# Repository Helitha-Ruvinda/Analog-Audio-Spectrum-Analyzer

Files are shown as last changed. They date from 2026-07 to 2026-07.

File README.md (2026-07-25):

# 10-Band Analog Audio Spectrum Analyzer

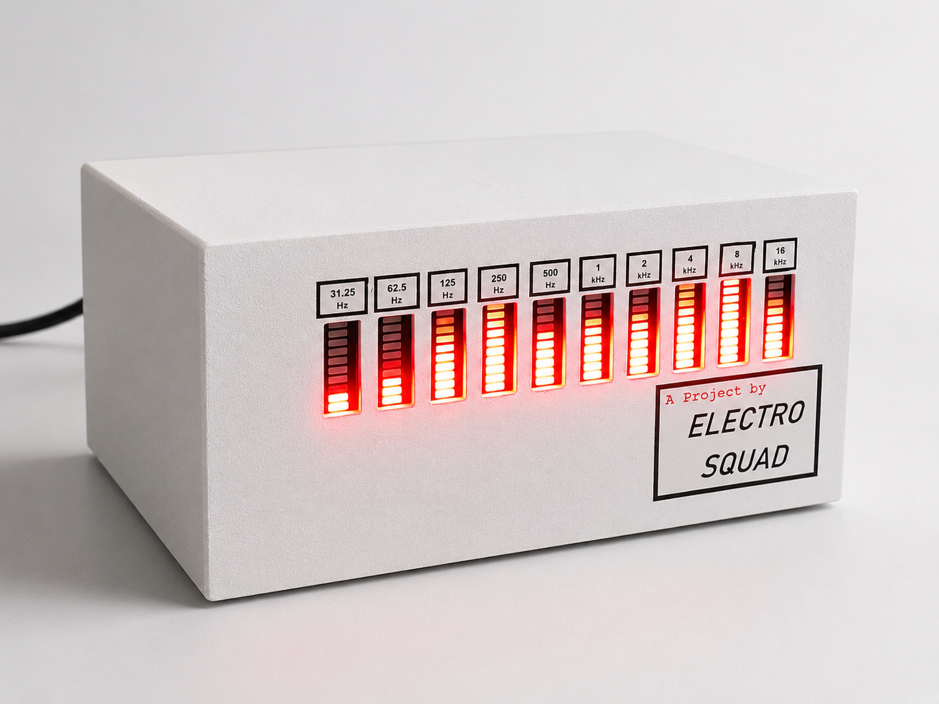
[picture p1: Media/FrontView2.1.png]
Project Front View


## Overview
This repository contains the complete hardware design, schematics, and testing documentation for a fully analog 10-band audio spectrum analyzer. The system processes incoming audio signals, isolates specific frequency bands, and visually maps the amplitude of each band using LED bar graphs. 

This project demonstrates full-stack analog hardware design from theoretical calculations to physical breadboard prototyping.

## Working Demonstration
Watch the fully analog analyzer in action below:

https://github.com/user-attachments/assets/5d2a667e-e02e-4562-982c-1e00bb6419e8

---

## System Architecture
The circuit avoids digital processing and relies entirely on precision analog components, divided into three core stages:

*   **Filter Stage:** Second-order Multiple Feedback (MFB) Band Pass Filters isolate 10 distinct audio frequency bands across the human hearing spectrum.
*   **Peak Detector Stage:** Precision Op-Amp based peak detectors capture the maximum amplitude of the filtered AC signals to provide a stable DC voltage for the display.
*   **Display Driver Stage:** LM3914 LED driver ICs, configured in "bar mode," map the analog voltage levels to 10-segment LED columns.

---

## Contribution
Team ElectroSquad
Department of Electronic and Telecommunication Engineering (ENTC)  
University of Moratuwa

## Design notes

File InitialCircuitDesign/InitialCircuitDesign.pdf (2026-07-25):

Single chanel

Filter.

This is a second order MFB (Multiple feed back Band Pass Filter). By changing R2, C1, C2, C3 we can change the cut-off frequency.

Peak Detector.

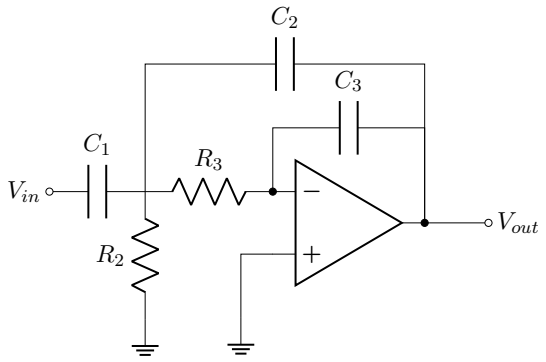
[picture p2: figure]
Vin; Vout

We need to examine how the peales change in each frequency component so that we can display them. for more reliable resault we use Op Amp based peale defector rather than single diode peale detector.

Comparator.

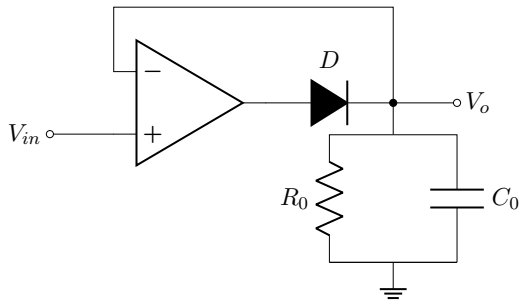
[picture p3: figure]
Vin

We need to map peale detector output to number of leds which is proportional to its amplitude. We could use Op amp compurators for this but for 10 bands which include 10 × 10 = 100 we require 100 opamps which is not practicle. Heance we use LM3914 IC has 10 comparators. This Ic has two modes. Dot & Bar mode. Let’s use bar mode for Visually apealling.

From Dadasheet;

1

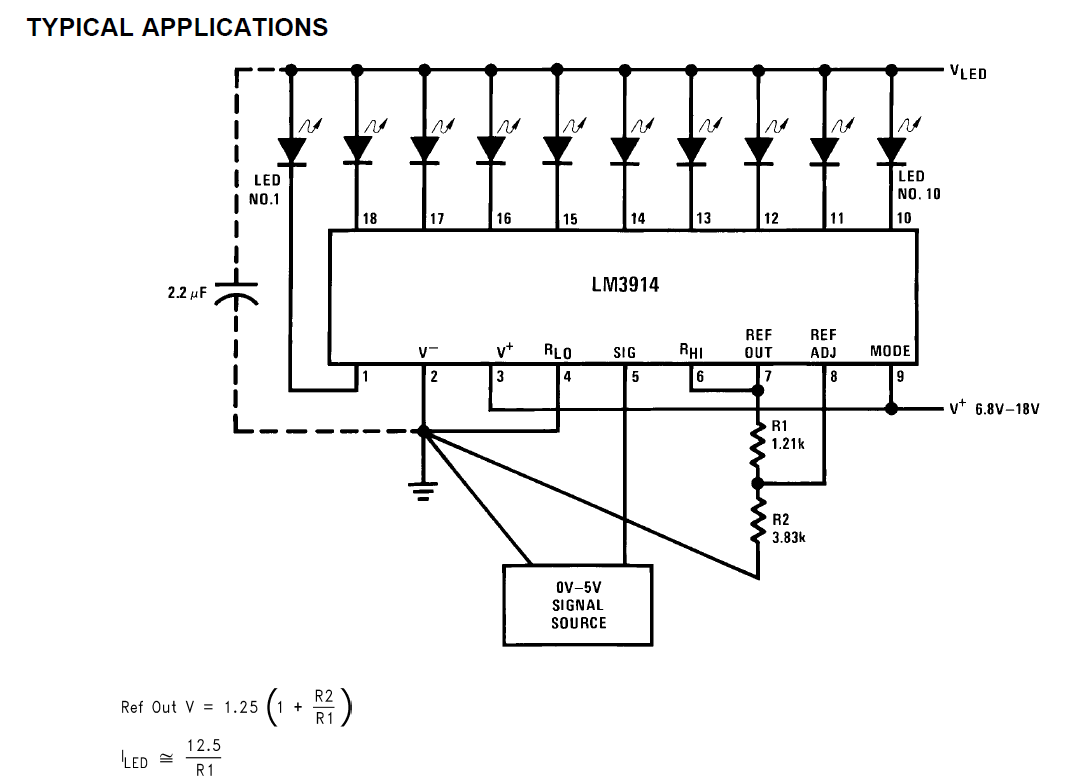
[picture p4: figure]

VRef = 1.25
1 +

R2
R1

ILED ∼=

12.5
R1

Since Audio source typical (Voud) max ≈ 2.5V Choose VRef = 2.5V = 1.25
1 + R2
R1

Hence R1 = R2

Choose current per led to be 10 mA

ILED = 10 mA =

12.5
R1

⇒ R1 = 1.25 kΩ

Combined Circuit per chanel.

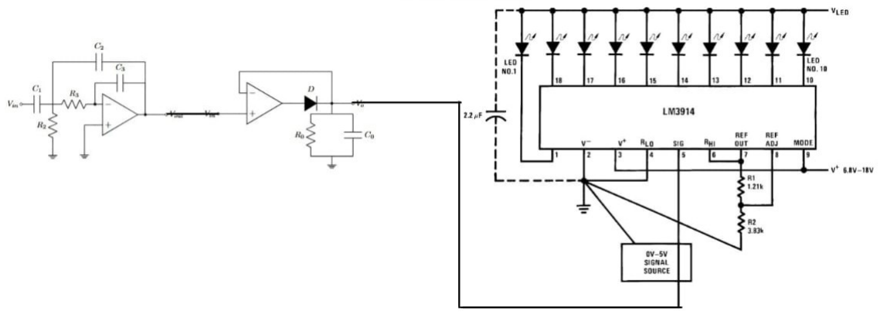
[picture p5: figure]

Repeat the above circuit to create 10 chanels. Diagram of full circuit.

2

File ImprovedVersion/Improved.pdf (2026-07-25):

## LED Matrix Display Using a Single LM3914

## Concept

Using ten LM3914 ICs is not space-efficient or cost-effective. Instead, a multiplexing technique can be employed so that a single LM3914 performs the same function.
By rapidly switching between channels, the analyzer can be extended to support up to 32 input channels while significantly reducing hardware cost and PCB area.

## System Overview

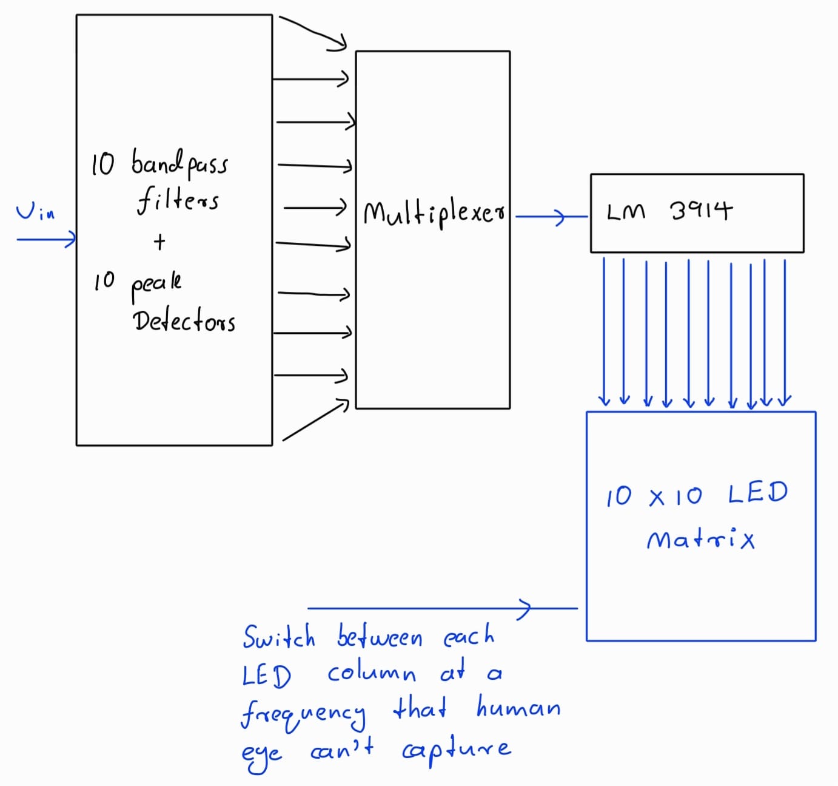
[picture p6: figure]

Figure 1: System for use single LM3914

## Operating Principle

- The input signal is divided into ten frequency bands using band-pass filters.

1

- Each filter output is processed by a peak detector.
- The ten peak voltages are sequentially selected by a multiplexer.
- The selected signal is fed into a single LM3914.
- The LM3914 drives one column of the LED matrix at a time.
- By rapidly scanning all columns, persistence of vision makes the display appear continuously illuminated.

## Advantages

- Lower component cost
- Reduced PCB area
- Easier routing
- Scalable architecture (up to 32 channels with additional multiplexing)
- Lower power consumption compared to using one LM3914 per channel

2

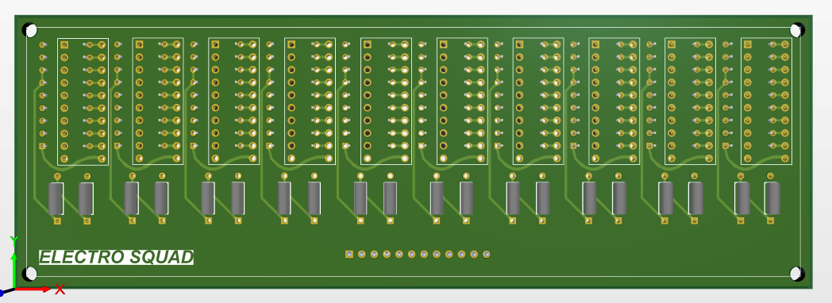
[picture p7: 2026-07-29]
DesignFiles/Altium/LedDriverCircuit-3D-Front.png

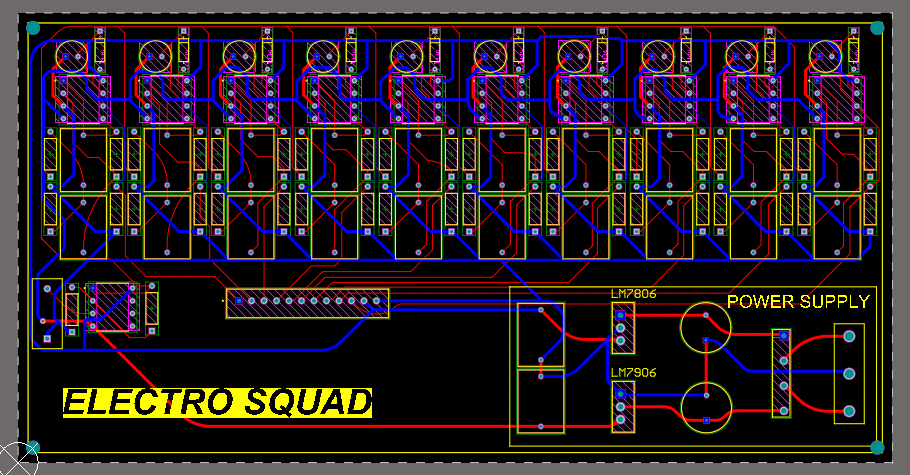
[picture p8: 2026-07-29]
DesignFiles/Altium/FilterCircuit-2D.png

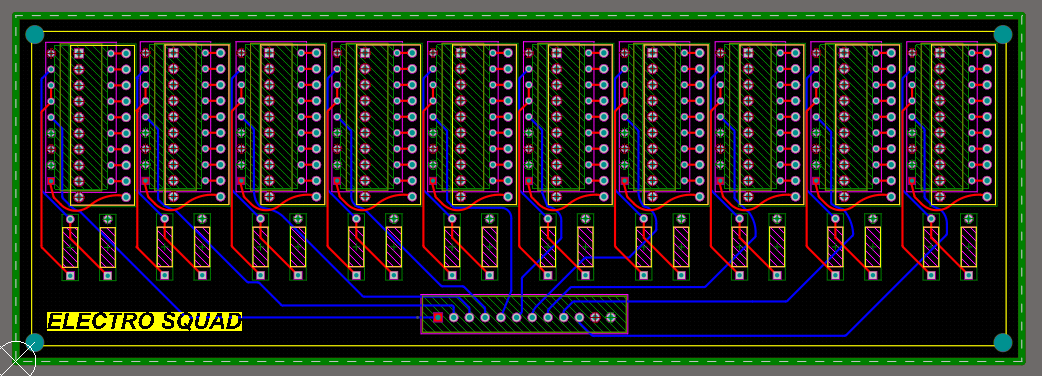
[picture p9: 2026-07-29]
DesignFiles/Altium/LedDriverCircuit-2D.png

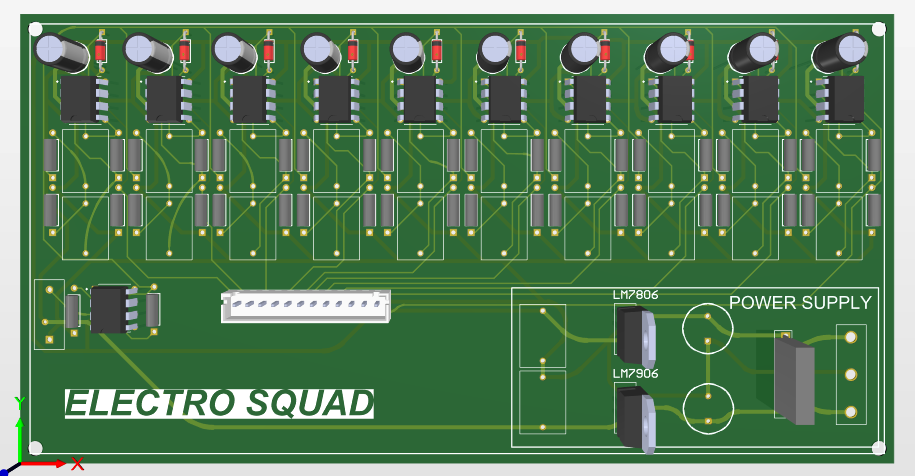
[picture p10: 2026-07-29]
DesignFiles/Altium/FilterCircuit-3D-Front.png

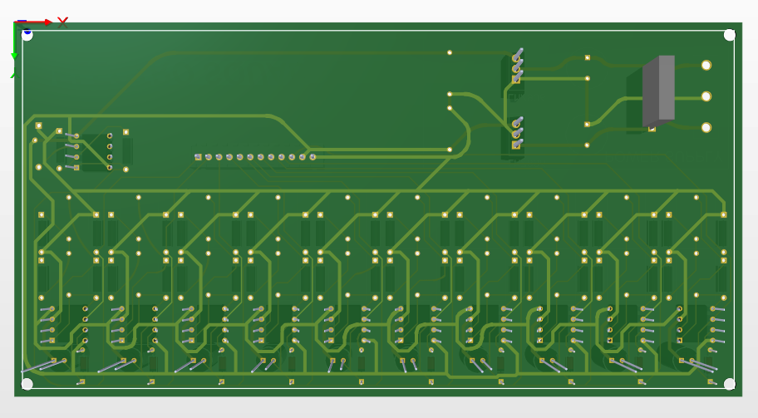
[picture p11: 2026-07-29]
DesignFiles/Altium/FilterCircuit-3D-Back.png

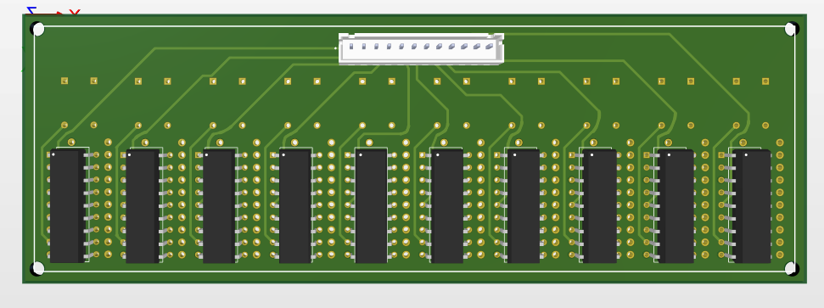
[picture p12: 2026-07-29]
DesignFiles/Altium/LedDriverCircuit-3D-Back.png

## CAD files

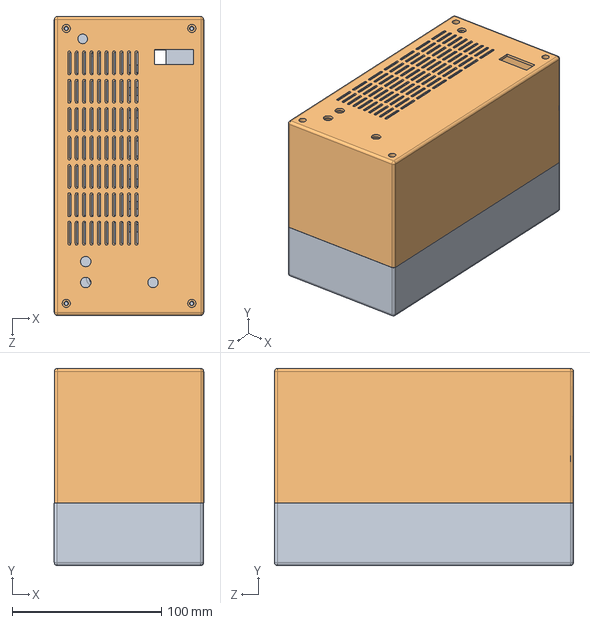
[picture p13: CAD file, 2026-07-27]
Enclosure Design/Assem.SLDASM
100.1 x 132.0 x 200.1 mm
Upper part
Lower part

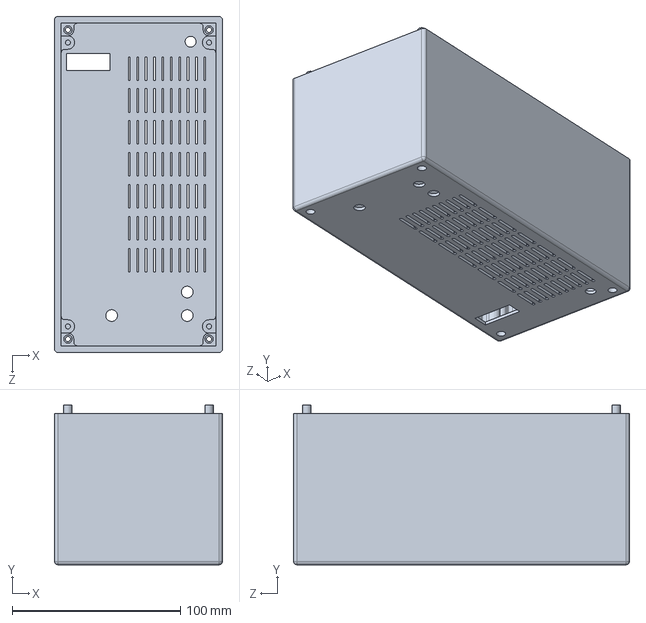
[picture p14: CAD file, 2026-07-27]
Enclosure Design/Lower part.SLDPRT
100.0 x 95.0 x 200.0 mm

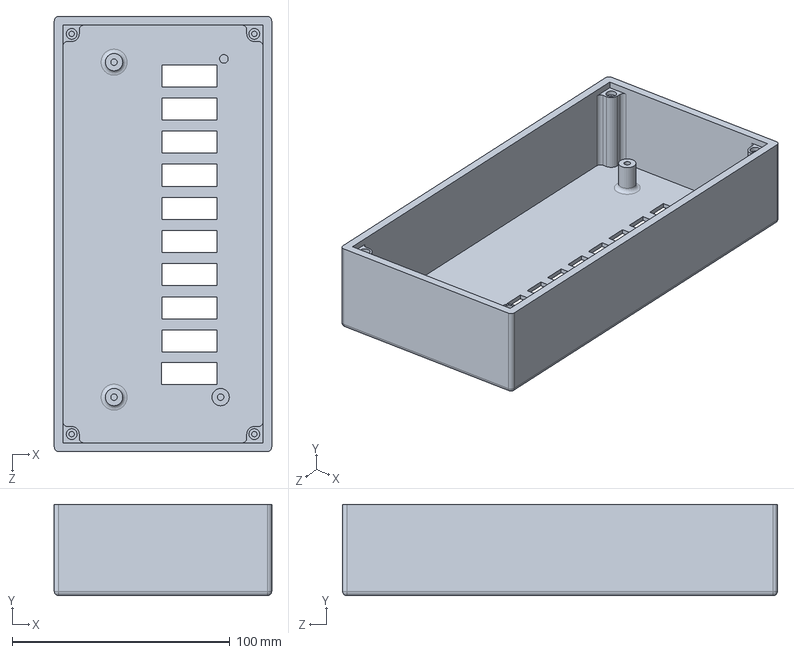
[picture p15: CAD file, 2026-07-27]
Enclosure Design/Upper part.SLDPRT
100.0 x 42.0 x 200.0 mm

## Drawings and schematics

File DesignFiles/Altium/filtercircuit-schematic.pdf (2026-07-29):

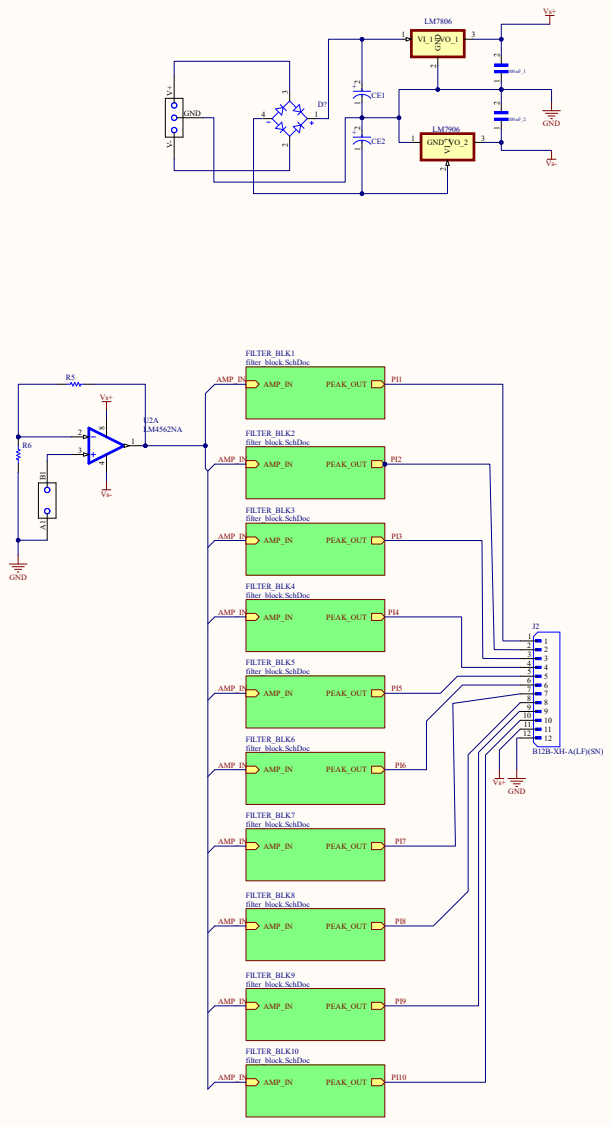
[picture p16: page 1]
Title; Size; Number; Revision; Date:; Sheet of; File:; D:\Documents\..\Filter_Main2.SchDoc; Drawn By:; GND; AMP_IN; PEAK_OUT; FILTER_BLK1 filter_block.SchDoc; FILTER_BLK2 filter_block.SchDoc; FILTER_BLK3 filter_block.SchDoc; FILTER_BLK4 filter_block.SchDoc; FILTER_BLK5 filter_block.SchDoc; FILTER_BLK6 filter_block.SchDoc; FILTER_BLK7 filter_block.SchDoc; FILTER_BLK8 filter_block.SchDoc; FILTER_BLK9 filter_block.SchDoc; FILTER_BLK10 filter_block.SchDoc; GND B¹ A¹; 3 GND 2

1

2

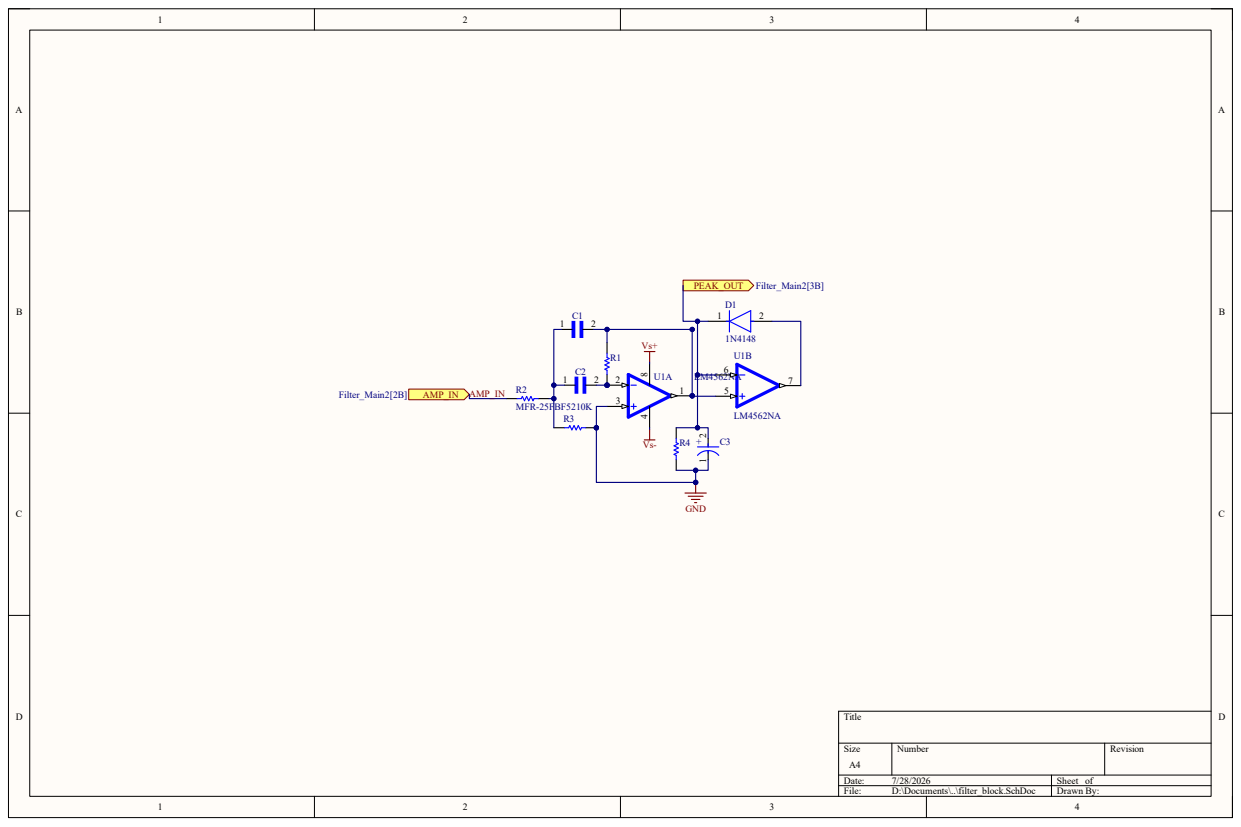
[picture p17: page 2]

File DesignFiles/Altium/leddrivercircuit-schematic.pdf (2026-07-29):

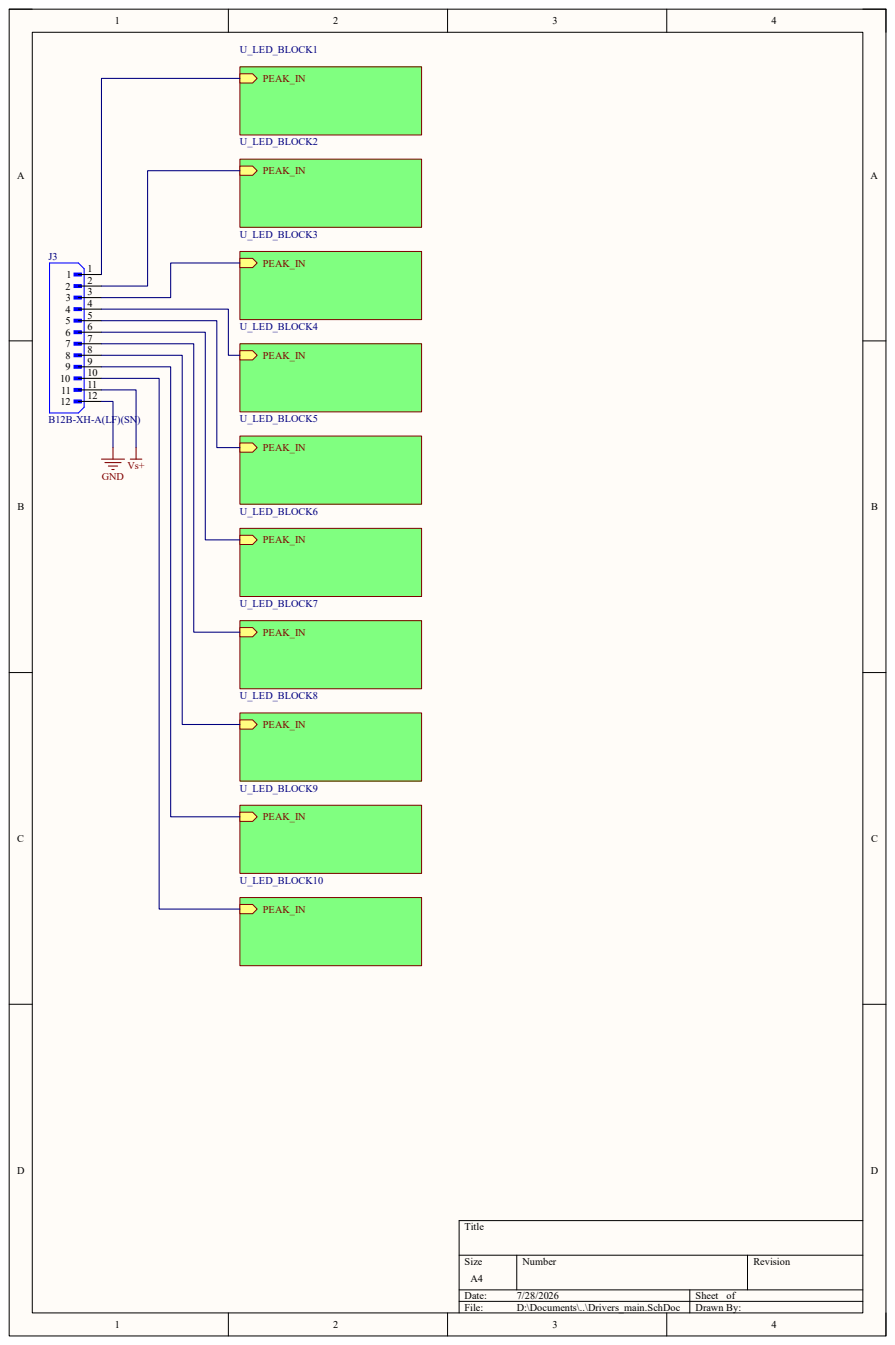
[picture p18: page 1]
Title; Size; Number; Revision; Date:; Sheet of; File:; D:\Documents\..\Drivers_main.SchDoc; Drawn By:; PEAK_IN; U_LED_BLOCK2; U_LED_BLOCK3; U_LED_BLOCK4; U_LED_BLOCK1; U_LED_BLOCK5; U_LED_BLOCK7; U_LED_BLOCK8; U_LED_BLOCK9; U_LED_BLOCK6; U_LED_BLOCK10; GND

1

2

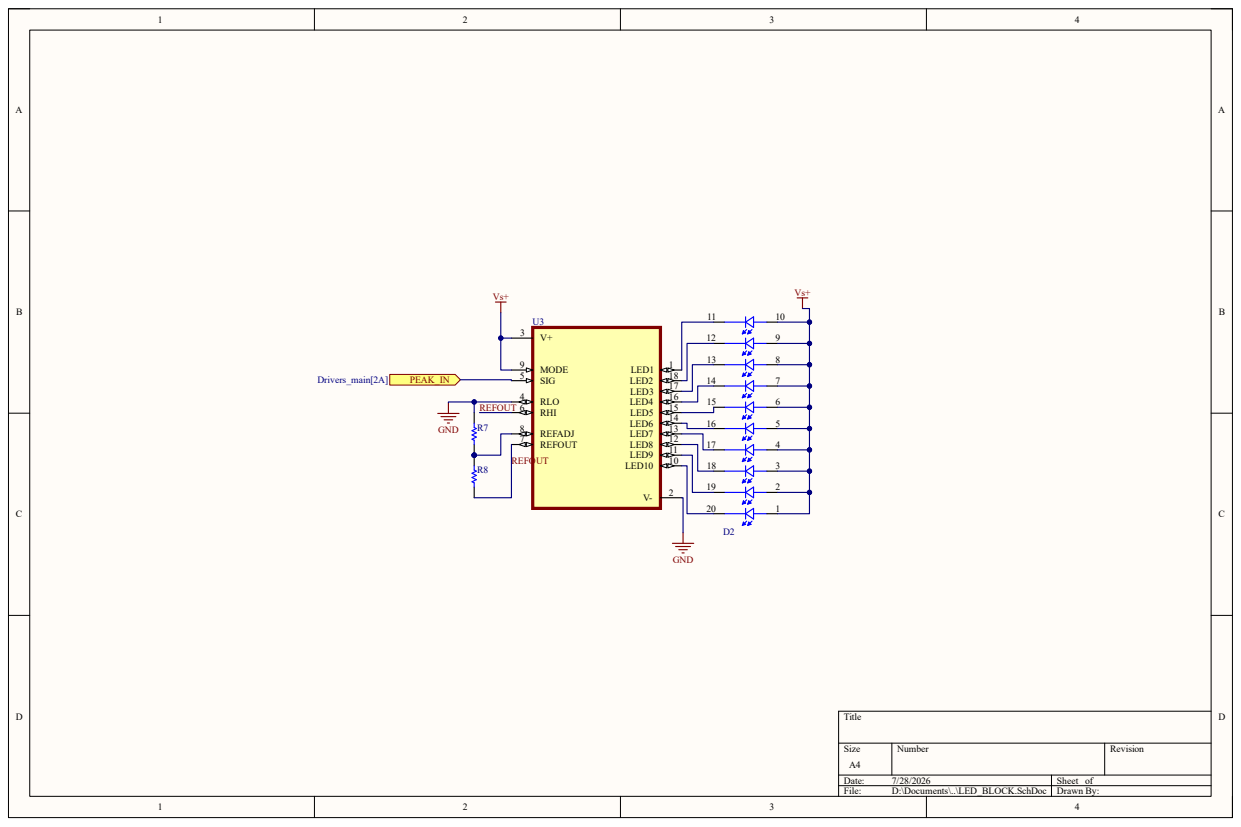
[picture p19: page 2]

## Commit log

2026-07-25 Create Initial Circuit Design
2026-07-25 Create PCB
2026-07-25 Create EnclosureDesign
2026-07-25 Added README template, Media files, and prototype testing video
2026-07-27 Adding LedDriverCircuit altium files
    [Drivers_main.SchDoc, LED_BLOCK.SchDoc, LED_Driver.PrjPcb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]
2026-07-27 Added Altium files for filters PCB
    [Filter_Main2.PcbDoc, Filter_Main2.SchDoc, Spectrum Analyzer2.PrjPcb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]
2026-07-27 Rename DesignFiles/Altium/Project Outputs for Spectrum Analyzer2.zip to DesignFiles/Altium/FilterCircuit/Project Outputs for Spectrum Analyzer2.zip
2026-07-27 Rename DesignFiles/Altium/Spectrum Analyzer.BomDoc to DesignFiles/Altium/FilterCircuit/Spectrum Analyzer.BomDoc
2026-07-27 Move Spectrum Analyzer2.PrjPcb to FilterCircuit directory
    [Spectrum Analyzer2.PrjPcb]
2026-07-29 PCB design and schematics
2026-07-29 Rename DesignFiles/Altium/Screenshot 2026-07-28 213910.png to DesignFiles/LedDriverPCB-2D.png
